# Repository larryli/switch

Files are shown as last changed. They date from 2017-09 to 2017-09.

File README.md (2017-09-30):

# 智能开关

Wifi 遥控开关，最多支持 9 路开关，高低电平触发均可。默认采用 2 路低电平触发继电器，并开启调试。

可以支持外红遥控，与 0.96 寸 I2C OLED 显示屏。

## 硬件

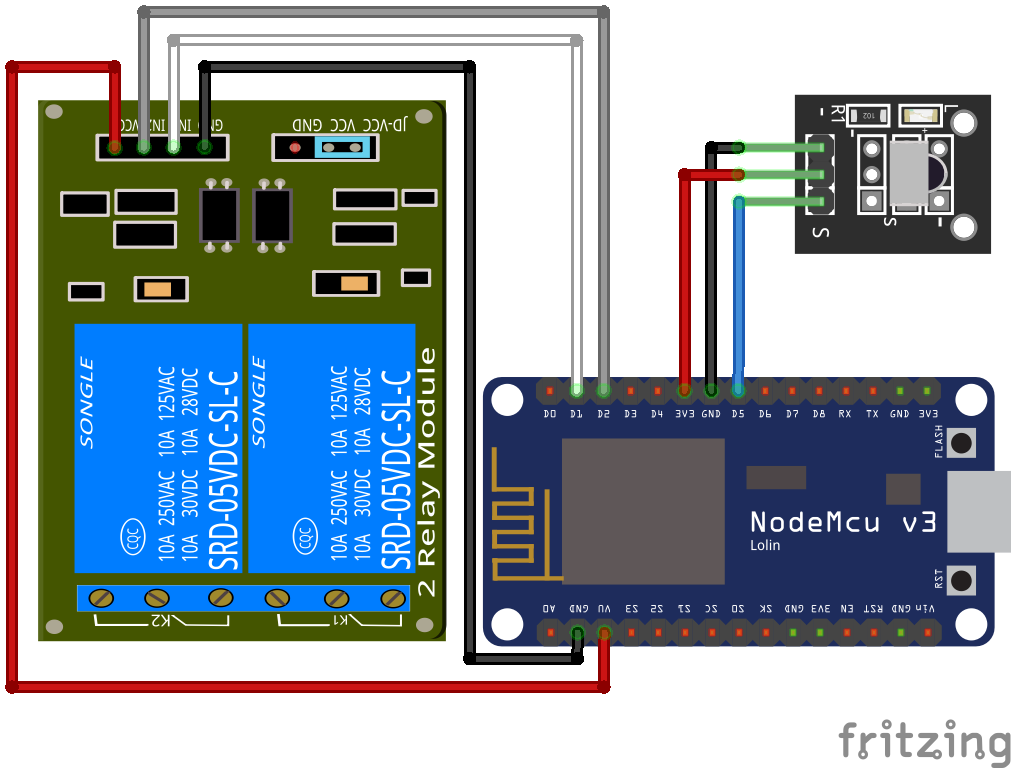
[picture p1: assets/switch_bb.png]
面包板接线图


建议物料清单：

- NodeMCU v3 开发板（板载 D4 Led、D3 Flash 与 Reset 按键）
- 2 通道低电平触发继电器（可选高电平触发，1 路、4 路、双 4 路）
- HX1838 红外接收头模块（需 CarMP3 21 键遥控器，NEC 编码）
- 母对母杜邦线 7 条

附加物料清单：

- 0.96 寸 128x64 SSD1306 I2C OLED 显示屏
- 母对母杜邦线 4 条

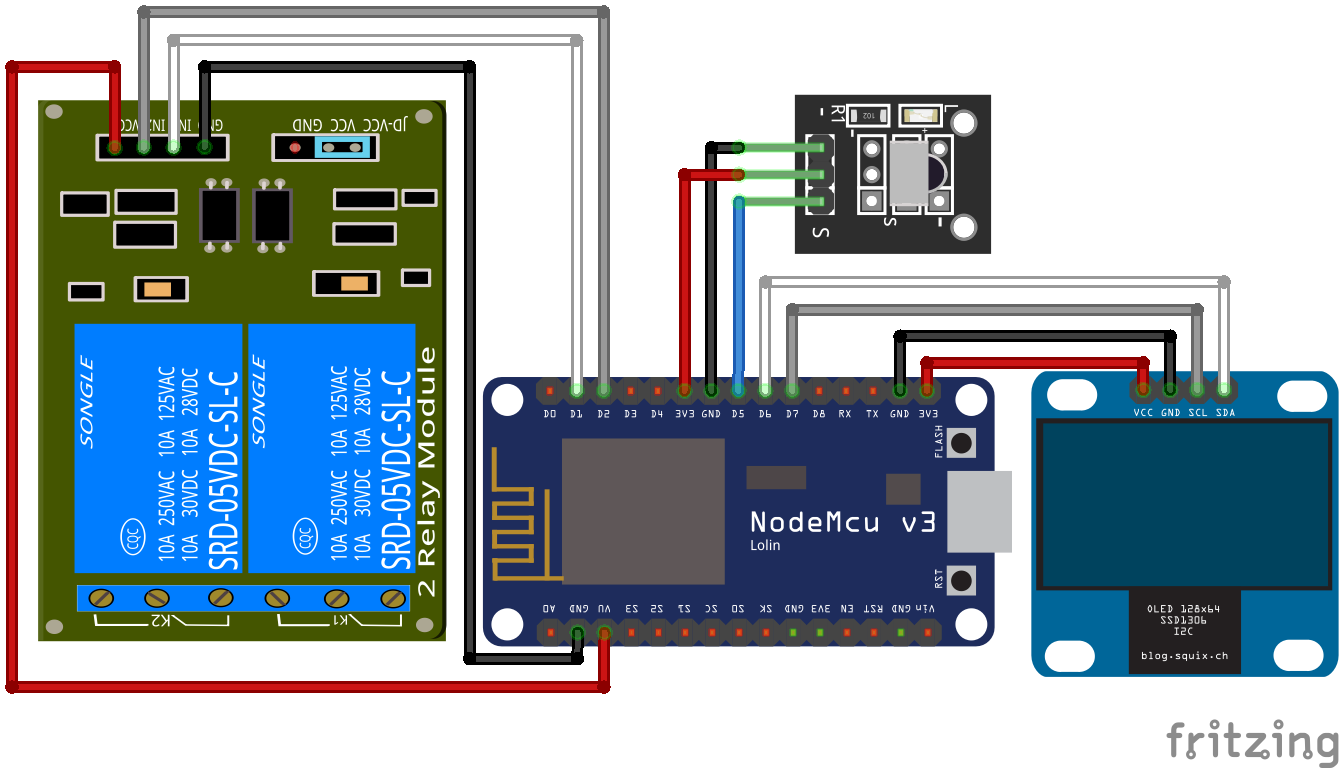
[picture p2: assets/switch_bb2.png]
附加面包板接线图


说明：

- NodeMCU v3 开发板 ESP6288 12F 板载 Led 接在 D4(GPIO2)，低电平触发
- NodeMCU v3 开发板板载 Flash 按键接在 D3(GPIO0)，低电平触发
- NodeMCU v3 开发板板载 Reset 按键接在 RST，低电平触发
- 默认的 2 路继电器，IN1 和 IN2 依次接在 D1(GPIO5) 和 D2(GPIO4)
- 默认开启的调试串口 RX 在 D9(GPIO3)（未用），TX 在 D10(GPIO1)
- 可选的红外接收头数据 D0 接在 D5(GPIO14)
- 可选的 I2C 显示屏 SDA 接在 D6(GPIO12)，SCL 接在 D7(GPIO13)
- 9 路继电器顺序依次为：D1、D2、D5、D6、D7、D0、D9、D8、D10，其中 D5、D6、D7、D10 被占用将被跳过
- MTDO D8(GPIO15) 在上电时需要置低电平，使用低电平触发继电器会出现额外的激活，详见[启动进程](https://github.com/esp8266/esp8266-wiki/wiki/Boot-Process)说明
- TX D10(GPIO1) 在上电时更是会切换高低电平，使用任何继电器都会出现额外的激活。不建议使用

## 软件

可以去掉 [`switch.h`](switch.h) 开头的注释：

- `#define SWITCH_COUNT 9` 继电器数量，默认为 2
- `#define SWITCH_TRIG_HIGH` 继电器高电平触发，默认为低电平触发
- `#define SWITCH_NO_IR` 关闭红外遥控，默认开启红外遥控
- `#define SWITCH_NO_OLED` 关闭显示屏，默认开启显示屏
- `#define SWITCH_NO_DEBUG` 关闭调试输出，默认开启 TX0 调试输出
- `#define SWITCH_NAME "SWITCH_"` mDNS 名称前缀，后面会加上 Wifi Mac 地址后三位，用于识别设备
- `#define SWITCH_SERV "http_switch"` mDNS 服务名，用于局域网发现设备

## 网络接口

参见[网络接口文档](network.md)。

### 板载按键

- 点击板载 Reset 按键硬件重启
- 按住板载 Flash 按键 3 秒以上再释放，清除配网重启

### 板载 LED

LED 状态 | 说明
:-------:|----
快闪 2 下，亮 0.5 秒 | 正在联网
常亮 | 联网正常
慢闪，亮 0.5 秒，灭 1.5 秒 | 联网错误
持续快闪 | 配网状态
闪 1 下 | 开关动作（只在网络正常时反馈）

### 21 键遥控器（NEC 编码）

- `1`…`8` 键对应 1…8 路继电器切换状态
- `0` 键全关所有继电器
- `100+` 键全开所有继电器
- 按住 `EQ` 键 2 秒清除配网重启

 按键  | 数值     | 按键  | 数值     | 按键  | 数值
:-----:|---------:|:-----:|---------:|:-----:|---------:
 `CH-` | 0xFFA25D | `CH`  | 0xFF629D | `CH+` | 0xFFE21D
 ⏮   | 0xFF22DD | ⏭   | 0xFF02FD | ⏯   | 0xFFC23D
 `-`   | 0xFFE01F | `+`   | 0xFFA857 | `EQ`  | 0xFF906F
 `0`   | 0xFF6897 | `100+`| 0xFF9867 | `200+`| 0xFFB04F
 `1`   | 0xFF30CF | `2`   | 0xFF18E7 | `3`   | 0xFF7A85
 `4`   | 0xFF10EF | `5`   | 0xFF38C7 | `6`   | 0xFF5AA5
 `7`   | 0xFF42BD | `8`   | 0xFF4AB5 | `9`   | 0xFF52AD

## 参考

- [8 Relay Control With NodeMCU and IR Receiver](http://www.instructables.com/id/8-Relay-Control-With-NodeMCU-and-IR-Receiver-Using/)
- [Using ESP8266 GPIO0/GPIO2/GPIO15](https://www.forward.com.au/pfod/ESP8266/GPIOpins/index.html)

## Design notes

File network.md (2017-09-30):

# 智能开关网络接口

## 配网

设备在没有 Wifi 网络连接信息配置（即未配网）时会进入配网状态，此时支持微信 AirKiss 和乐鑫 EspTouch 两种自动配网协议。无需设备切换到 AP 状态即可轻松配网。

**注意**：默认不支持微信 AirKiss 的 AES128-CBC 加密 Wifi 密码的配置。如需支持，请额外处理收到的加密密码并解密，然后手工连接网络。

## 局域网发现

一般情况下，设备在连接 Wifi 后都会由 DHCP 分配一个动态局域网 IP 地址。需要解决设备发现（确定其 IP），和设备识别（IP 是不固定的）问题。

设备在连接 Wifi 成功后，会使用 mDNS 协议注册自己以及特定的服务。其中：

- **设备发现**：默认编译会注册到 `_http_switch._tcp.local.` 服务，将会找到设备注册名。同类型的不同设备都会注册到此服务，所以可能会找到多个设备。
- **设备识别**：默认编译会注册 `SWITCH_XXYYZZ.local` 名称，其中 `XXYYZZ` 为 6 位 Mac 地址后 3 位，通过名称可以反查到设备的局域网 IP，同时使用不同的名称识别不同的设备。同类型的不同设备具有不同的 Mac 地址后缀。

## HTTP Restful 接口

设备在连接 Wifi 成功后，会在 80 端口开启 HTTP 服务。

### Restful 通用返回说明

默认返回相应为 `appliction/json`。

- HTTP 状态码：`200` 成功
- HTTP 状态码：`404` 找不到指定的资源
- HTTP 状态码：`422` 请求参数错误
- 返回数据：`success` 整数，`0` 或 `1`，即请求失败或成功
- 返回数据：`message` 字符串，请求失败时的简要错误信息

### `GET /switch` 获取开关状态

- 必需参数：无
- 可选参数：`switch` 整数，为开关编号，从 `1` 开始计数，不超过编译规定的最大开关数目；没有提供此参数时将返回所有开关状态数组
- 返回数据：`success` 整数，`0` 或 `1`，下面的数据只在 `1` 时返回
- 返回数据：`switch` 整数，为开关编号；请求提供 `switch` 参数时返回
- 返回数据：`state` 整数，`0` 或 `1`，即开关已关闭或已打开状态；请求提供 `switch` 参数时返回
- 返回数据：`switches` 数组，包含所有开关的 `switch` 与 `state` 数据；请求未提供 `switch` 参数时返回

### `POST /switch` 修改开关状态

- 必需参数：`state` 整数，`0` 或 `1`，即关闭开关或打开开关
- 可选参数：`switch` 整数，为开关编号，从 `1` 开始计数，不超过编译规定的最大开关数目；没有提供此参数时将修改所有开关
- 可选参数：`switches` 整数，`0` 或 `1`；提供此参数，且为 `1` 将会返回额外的所有开关状态数组，为 `0` 时只返回 `success`
- 返回数据：`success` 整数，`0` 或 `1`，下面的数据只在 `1` 时返回
- 返回数据：`switch` 整数，为开关编号；请求提供 `switch` 参数时返回
- 返回数据：`state` 整数，`0` 或 `1`，即开关已关闭或已打开状态；请求提供 `switch` 参数时返回
- 返回数据：`switches` 数组，包含所有开关的 `switch` 与 `state` 数据；请求未提供 `switch` 参数时或提供 `switches` 参数时返回

## SSE 事件通知

设备提供 Server-Sent Events 接口，当开关状态发生变化时通知消息。

### `/events` 消息

- 返回数据：`success` 整数，兼容 Restful 接口，只会返回 `1`
- 返回数据：`switches` 数组，包含所有开关的 `switch` 与 `state` 数据，详见 Restful 接口说明

## HTTP 直接操作

直接访问设备 IP 地址 80 端口，提供 HTML5 操作界面。

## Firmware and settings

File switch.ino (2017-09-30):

///
// 主程序，开关处理逻辑
//

#include "switch.h"

///
// 主配置入口
//
void setup()
{
  debug_setup();
  _switch_setup();
  led_setup();
  reset_setup();
#ifdef SWITCH_IR
  irrecv_setup();
#endif
#ifdef SWITCH_OLED
  oled_setup();
#endif
  mdns_setup();
  wifi_setup();
  server_setup();
}

///
// 主循环入口
//
void loop()
{
#ifdef SWITCH_OLED
  oled_loop();
#endif
#ifdef SWITCH_IR
  if (irrecv_loop()) {
    return;
  }
#endif
  if (wifi_loop()) {
    return;
  }
}

///
// 开关事件处理
//
void switch_event(const Event e)
{
  _switch_event(e);
  wifi_event(e);
  mdns_event(e);
  led_event(e);
#ifdef SWITCH_OLED
  oled_event(e);
#endif
  server_event(e);
  reset_event(e);
}

///
// 配置开关
//
static void _switch_setup()
{
  for (int i = 0; i < SWITCH_COUNT; i++) {
    pinMode(SWITCHES[i], OUTPUT);
    digitalWrite(SWITCHES[i], SWITCH_OFF);
  }
}

///
// 开关自身事件处理
//
static void _switch_event(const Event e)
{
  switch (e) {
    case EVENT_RESTART:
      ESP.restart();
      return;
    case EVENT_ON:
      for (int i = 0; i < SWITCH_COUNT; i++) {
        _switch_turn(i, true);
      }
      break;
    case EVENT_OFF:
      for (int i = 0; i < SWITCH_COUNT; i++) {
        _switch_turn(i, false);
      }
      break;
    default:
      if (e >= EVENT_1 && e <= EVENT_9) {
        _switch_toggle(e - EVENT_1);
      } else if (e >= EVENT_1_ON && e <= EVENT_9_ON) {
        _switch_turn(e - EVENT_1_ON, true);
      } else if (e >= EVENT_1_OFF && e <= EVENT_9_OFF) {
        _switch_turn(e - EVENT_1_OFF, false);
      } else {
        return;
      }
      break;
  }
  switch_event(EVENT_REFRESH);
}

///
// 切换开关状态
// @param unsigned int i 开关索引
// @return bool 开关是否已打开
//
static bool _switch_toggle(const uint8_t i)
{
  if (i < SWITCH_COUNT) {
    int data = !digitalRead(SWITCHES[i]);
    bool state = (data == SWITCH_ON);

    debug_print(F("[DEBUG] Switch #"));
    debug_print(i + 1);
    debug_println(state ? F(" on") : F(" off"));
    digitalWrite(SWITCHES[i], data);
    return state ? true : false;
  }
  return false;
}

///
// 打开/关闭开关
// @param unsigned int i 开关索引
// @param bool state 打开/关闭开关
// @return bool 是否操作成功
//
static bool _switch_turn(const uint8_t i, const bool state)
{
  if (i < SWITCH_COUNT) {
    int data = digitalRead(SWITCHES[i]);

    if (state) {
      if (data == SWITCH_OFF) {
        debug_print(F("[DEBUG] Switch #"));
        debug_print(i + 1);
        debug_println(F(" on"));
        digitalWrite(SWITCHES[i], SWITCH_ON);
        return true;
      }
    } else if (data == SWITCH_ON) {
      debug_print(F("[DEBUG] Switch #"));
      debug_print(i + 1);
      debug_println(F(" off"));
      digitalWrite(SWITCHES[i], SWITCH_OFF);
      return true;
    }
  }
  return false;
}

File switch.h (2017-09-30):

///
// switch.h
// 去掉注释可以设置相应选项
//

#ifndef _SWITCH_H
#define _SWITCH_H

//#define SWITCH_COUNT 9             // 继电器数量
//#define SWITCH_TRIG_HIGH           // 继电器高电平触发
//#define SWITCH_NO_IR               // 关闭红外遥控
//#define SWITCH_NO_OLED             // 关闭显示屏
//#define SWITCH_NO_DEBUG            // 关闭调试输出
//#define SWITCH_NAME "SWITCH_"      // mDNS 名称前缀
//#define SWITCH_SERV "http_switch"  // mDNS 服务名

#include <ESP8266WiFi.h> // @see https://github.com/esp8266/Arduino
#include <ESPAsyncWebServer.h> // @see https://github.com/me-no-dev/ESPAsyncWebServer
#include <Ticker.h>

#ifndef SWITCH_NAME
# define SWITCH_NAME "SWITCH_"       // mDNS 名称前缀
#endif
#ifndef SWITCH_SERV
# define SWITCH_SERV "http_switch"   // mDNS 服务名
#endif

#ifndef SWITCH_TRIG_LOW
# ifndef SWITCH_TRIG_HIGH
#  define SWITCH_TRIG_LOW            // 继电器低电平触发
# endif
#endif
#ifdef SWITCH_TRIG_LOW
# define _D_LOW_
# define _N_LOW_ 0
# define SWITCH_ON LOW
# define SWITCH_OFF HIGH
#else
# define _D_LOW_ D8,
# define _N_LOW_ 1
# define SWITCH_ON HIGH
# define SWITCH_OFF LOW
#endif

const uint8_t WIFI_LED = D4;
const uint8_t RESET_BTN = D3;

#ifndef SWITCH_IR
# ifndef SWITCH_NO_IR
#  define SWITCH_IR                  // 开启红外
# endif
#endif
#ifdef SWITCH_IR
# define _D_IR_
# define _N_IR_ 0
const uint8_t IR_RECV = D5;
#else
# define _D_IR_ D5,
# define _N_IR_ 1
#endif

#ifndef SWITCH_OLED
# ifndef SWITCH_NO_OLED
#  define SWITCH_OLED                // 开启显示屏
# endif
#endif
#ifdef SWITCH_OLED
# define _D_OLED_
# define _N_OLED_ 0
const uint8_t OLED_SDA = D6;
const uint8_t OLED_SCL = D7;
#else
# define _D_OLED_ D6, D7,
# define _N_OLED_ 2
#endif

#ifndef SWITCH_DEBUG
# ifndef SWITCH_NO_DEBUG
#  define SWITCH_DEBUG               // 开启 TX0 调试输出
# endif
#endif
#ifdef SWITCH_DEBUG
# define _D_DEBUG_
# define _N_DEBUG_ 0
# define debug_setup() Serial.begin(115200);  \
Serial.println()
# define debug_print(...) Serial.print(__VA_ARGS__)
# define debug_println(...) Serial.println(__VA_ARGS__)
#else
# define _D_DEBUG_ D10,
# define _N_DEBUG_ 1
# define debug_setup() uart_set_debug(0)
# define debug_print(...)
# define debug_println(...)
#endif

#ifndef SWITCH_COUNT
# define SWITCH_COUNT 2              // 继电器数量
#endif
#define _N_COUNT_ (4+_N_IR_+_N_OLED_+_N_LOW_+_N_DEBUG_)
#if SWITCH_COUNT > _N_COUNT_
# define SWITCH_COUNT _N_COUNT_
#endif
const uint8_t SWITCHES[] = {D1, D2, _D_IR_ _D_OLED_ D0, D9, _D_LOW_ _D_DEBUG_};
#undef _D_IR_
#undef _D_OLED_
#undef _D_LOW_
#undef _D_DEBUG_

typedef enum {
  EVENT_CONNECTING, EVENT_CONNECTED, EVENT_FAILED, EVENT_DISCONNECTED,
  EVENT_CONFIG, EVENT_RECEIVED,
  EVENT_RESET, EVENT_RESTART,
  EVENT_REFRESH,
  EVENT_ON, EVENT_OFF,
  EVENT_1, EVENT_2, EVENT_3, EVENT_4, EVENT_5, EVENT_6, EVENT_7, EVENT_8, EVENT_9,
  EVENT_1_ON, EVENT_2_ON, EVENT_3_ON, EVENT_4_ON, EVENT_5_ON, EVENT_6_ON, EVENT_7_ON, EVENT_8_ON, EVENT_9_ON,
  EVENT_1_OFF, EVENT_2_OFF, EVENT_3_OFF, EVENT_4_OFF, EVENT_5_OFF, EVENT_6_OFF, EVENT_7_OFF, EVENT_8_OFF, EVENT_9_OFF,
  EVENT_UP, EVENT_DOWN, EVENT_SELECT,
} Event;

// Switch
void switch_event(const Event e);

// Led
void led_setup();
void led_event(const Event e);

// Reset
void reset_setup();
void reset_event(const Event e);

#ifdef SWITCH_IR
// IR Recv
void irrecv_setup();
bool irrecv_loop();
#endif

#ifdef SWITCH_OLED
// OLED
void oled_setup();
void oled_loop();
void oled_event(const Event e);
#endif

// Wifi
void wifi_setup();
bool wifi_loop();
void wifi_event(const Event e);

// Server
void server_setup();
void server_event(const Event e);

// mDNS
void mdns_setup();
void mdns_event(const Event e);

#endif

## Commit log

2017-09-05 硬件接线图与物料清单
    [switch.fzz]
2017-09-06 增加固件编译配置
2017-09-06 处理按键与 LED 灯
2017-09-08 调整为红外控制和 Arduino 编程
    [switch.fzz]
2017-09-09 增加 arduino 代码
2017-09-11 增加代码
2017-09-11 调整 LED 显示逻辑
2017-09-11 增加文件
2017-09-12 调整 html js
2017-09-12 调整文档
2017-09-12 清除 master 代码
2017-09-12 增加 mDNS
2017-09-12 调整 mdns 名称和 wifi hostname
2017-09-12 页面优化
2017-09-12 JS 优化
2017-09-12 增加网络接口文档
2017-09-15 分拆代码，独立模块
2017-09-15 循环判断优化
2017-09-15 优化 RAM，修复 debug
2017-09-20 忽略 .vscode
2017-09-20 增加部分注释
2017-09-24 增加 OLED 显示
2017-09-26 调整 OLED 显示
    [switch.fzz]
2017-09-27 增加 async 处理
2017-09-27 http 优化
2017-09-27 更新文档
2017-09-27 移除无效代码
2017-09-27 JS SSE 优化与 reset bug 修正
    [oled.ino, reset.ino]
2017-09-28 HTTP 性能优化，JS 优化，CSS/JS 自动处理
    [switch.fzz]
2017-09-28 ETAG 处理
2017-09-28 优化 LED 显示
2017-09-28 修正 iOS 下按钮显示问题
2017-09-29 重构：采用事件统一处理状态变更，避免多个模块相互无序调用
2017-09-29 reset 处理调整
2017-09-29 mdns 事件处理
2017-09-29 增加 favicon.ico
2017-09-29 文档与预定义调整
2017-09-30 调整板载 reset 按钮逻辑
2017-09-30 调整红外遥控 reset 按钮逻辑
2017-09-30 reset 不阻塞
2017-09-30 修正清除配网 bug
2017-09-30 OLED 菜单功能
2017-09-30 清除上一次的菜单选择
2017-09-30 增加 OLED 自动关屏，优化关屏时刷新显示处理
